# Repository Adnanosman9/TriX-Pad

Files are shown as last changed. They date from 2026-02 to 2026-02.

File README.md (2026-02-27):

<h1 align="center">
  TriXpad
</h1>

<h4 align="center">
  A custom, open-source mechanical macro-pad featuring an OLED screen.
</h4>

<div align="center">

  
  
  

</div>

<br>

##  Key Features

* **Brain:** Powered by the compact and capable **Seeed Studio XIAO RP2040**.
* **Firmware:** Runs on **KMK Firmware** (CircuitPython) for incredibly easy keymap customization without needing to recompile.
* **Display:** Integrated **0.91" SSD1306 OLED (128×64)** for real-time layer feedback, stats, or custom graphics.
* **Matrix:** A clean **3×3 Key Matrix** layout complete with diode orientation for robust anti-ghosting.

---

## Hardware Design

This project was built entirely from scratch, bridging custom PCB design with 3D modeling. 

### PCB (KiCad)
The board was routed and designed in KiCad to keep the footprint as minimal as possible while accommodating the XIAO RP2040 and OLED screen.

| Schematic | PCB Layout | 3D Render |
| :---: | :---: | :---: |
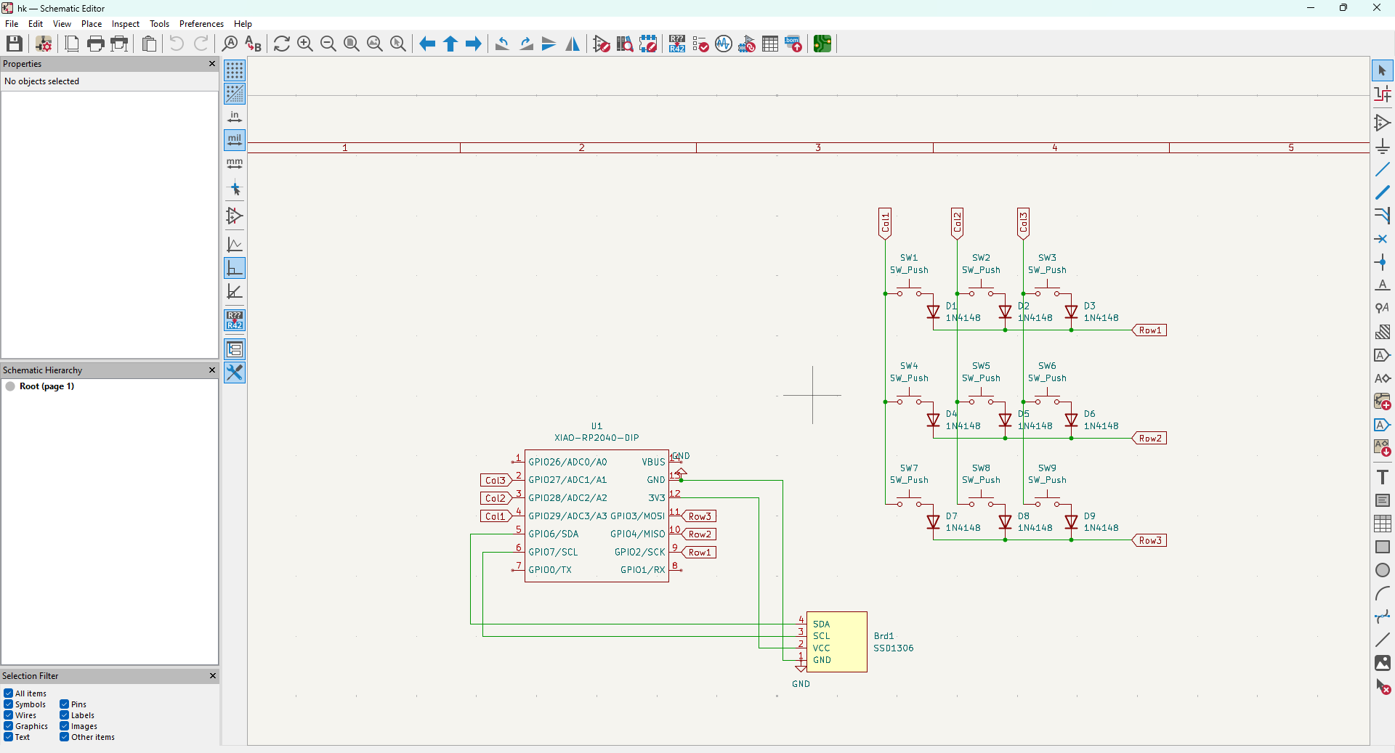
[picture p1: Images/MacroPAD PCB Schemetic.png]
Schematic
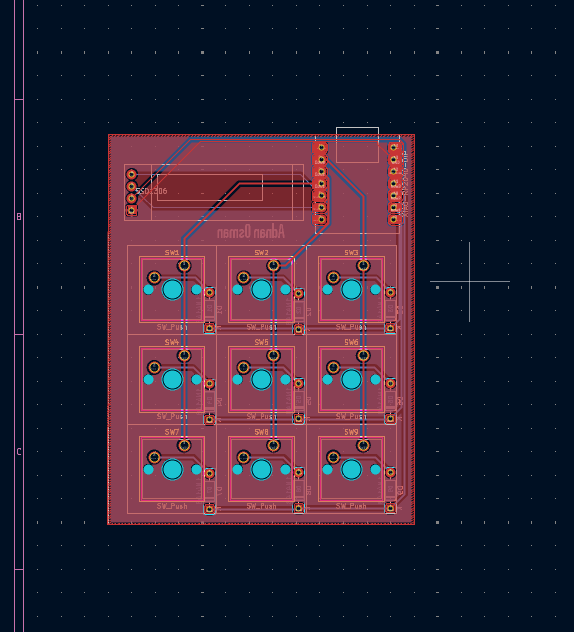
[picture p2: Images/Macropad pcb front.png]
PCB Front
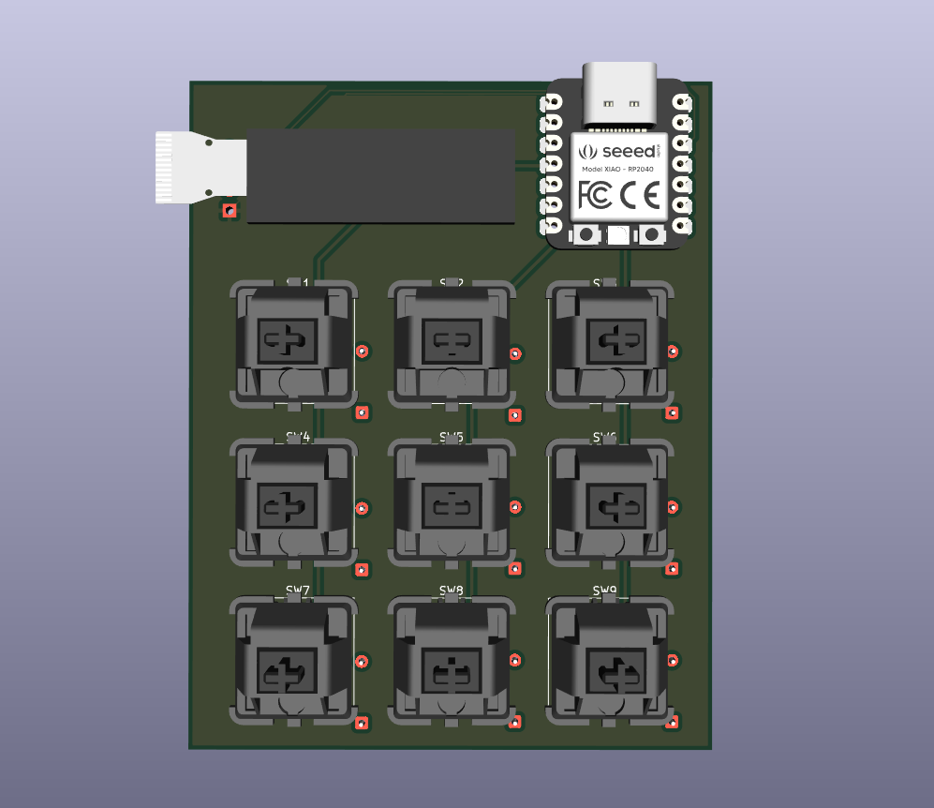
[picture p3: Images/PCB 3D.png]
PCB 3D
|  |  |  |

### Case (Fusion 360)
The enclosure was designed in Autodesk Fusion 360—marking my very first time diving into CAD! It features a sleek, two-part snap-fit/screw design to house the PCB and switches securely.

| Top Case | Bottom Case |
| :---: | :---: |
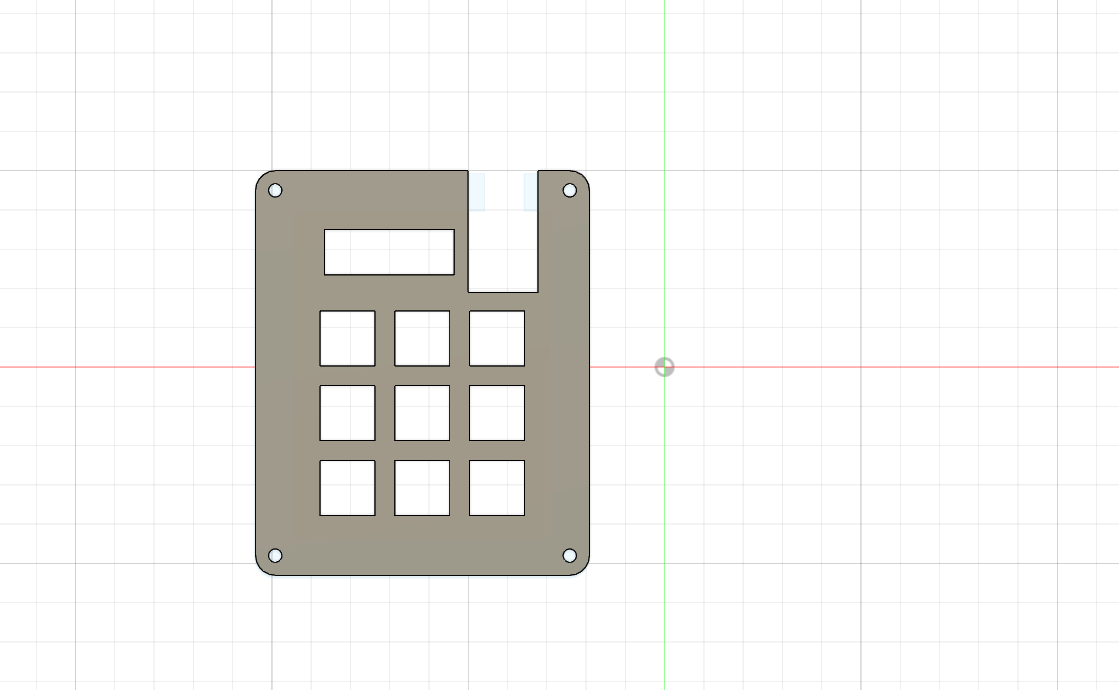
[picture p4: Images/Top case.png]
Case Top
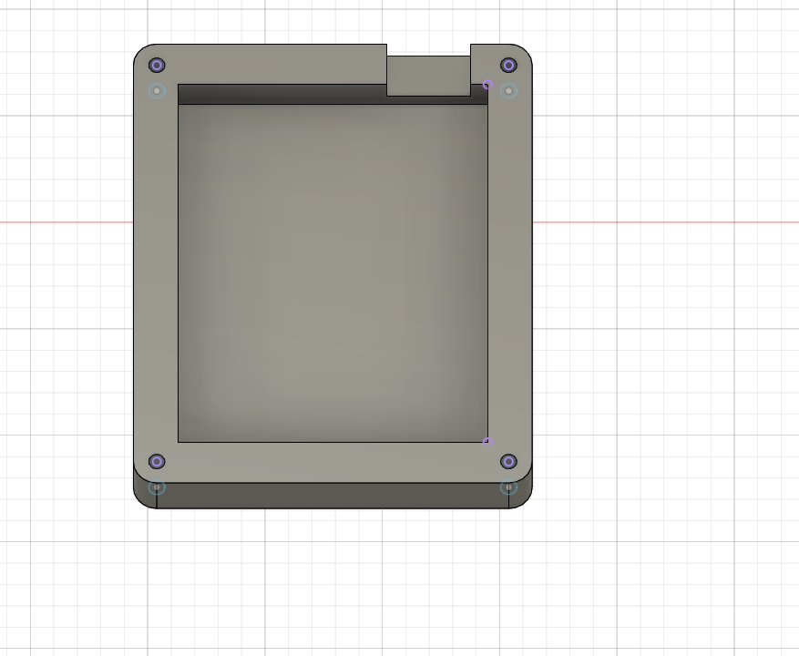
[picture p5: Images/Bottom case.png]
Case Bottom
|  |  |

###  The Final Build
<div align="center">
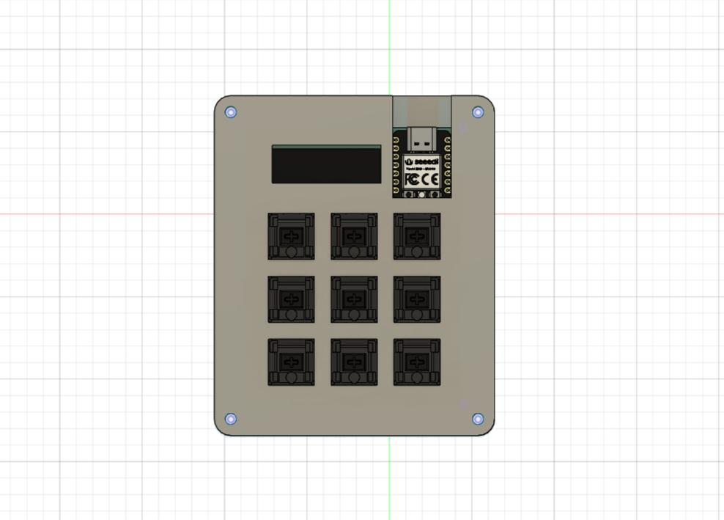
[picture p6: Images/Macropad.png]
Final Build
  
</div>

---

##  Bill of Materials (BOM)

Everything you need to build this macro-pad yourself. *(For full details, see the [`BOM.csv`](BOM.csv) file).*

| Component | Description / Item | Qty | Source |
| :--- | :--- | :---: | :--- |
| **Controller** | Seeed Studio XIAO RP2040 | 1 | [AliExpress](https://www.aliexpress.com/item/1005003901735765.html) |
| **Switches** | MX-Style (Cherry) | 9 | [AliExpress](https://www.aliexpress.com/item/1005008656717678.html) |
| **Display** | 0.91" SSD1306 OLED | 1 | [AliExpress](https://www.aliexpress.com/item/1005009334190029.html) |
| **Diodes** | 1N4148 Through-Hole | 9 | [Robotics BD](https://store.roboticsbd.com/components/1355-1n4148-diode-robotics-bangladesh.html) |
| **Keycaps** | Blank DSA Keycaps (Black) | 9 | [AliExpress](https://www.aliexpress.com/item/1005006114411137.html) |

---

##  Credits & Acknowledgments

This project wouldn't be possible without these incredible open-source tools and communities:

* **[KiCad](https://www.kicad.org/)** for the phenomenal open-source PCB design suite.
* **[Autodesk Fusion 360](https://www.autodesk.com/products/fusion-360/)** for the case design environment.
* **[Hack Club Blueprint](https://blueprint.hackclub.com/)** for the guide and inspiration. 
* Massive thanks to **Hack Club Bank** for the grant that funded the PCB and case manufacturing to bring this hardware to life!

<br>

<div align="center">
  Approved by Hack Club
  <br><br>
  <b>Designed by <a href="https://github.com/Adnanosman9">@Adnanosman</a></b>
</div>

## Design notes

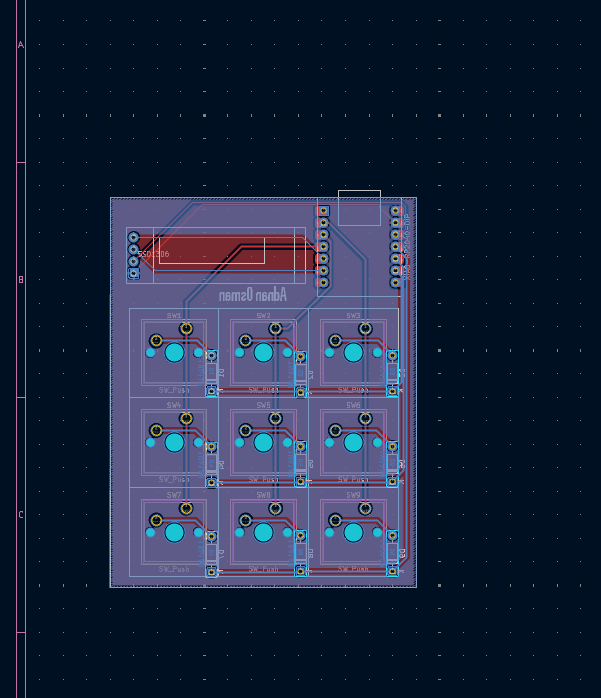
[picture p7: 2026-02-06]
Images/Macropad PCB back.png

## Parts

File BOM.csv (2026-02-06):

Component | Item | Quantity | Link
Controller | Seeed Studio XIAO RP2040 | 1 | https://www.aliexpress.com/item/1005003901735765.html?curPageLogUid=IyM167uC5ZPL
Switches | MX-Style -Cherry | 9 | https://www.aliexpress.com/item/1005008656717678.html?curPageLogUid=WpvRvEpise9v
Display | 0.91" SSD1306 OLED | 1 | https://www.aliexpress.com/item/1005009334190029.html?curPageLogUid=FVxMMdBZr2ks
Diodes | 1N4148 | 9 | https://store.roboticsbd.com/components/1355-1n4148-diode-robotics-bangladesh.html
Keycaps | Blank DSA Keycaps(Black) | 9 | https://www.aliexpress.com/item/1005006114411137.html?curPageLogUid=FdgYhFJXMlbC
PCB |  | 1 | https://www.nextpcb.com/?code=BanglaGECS

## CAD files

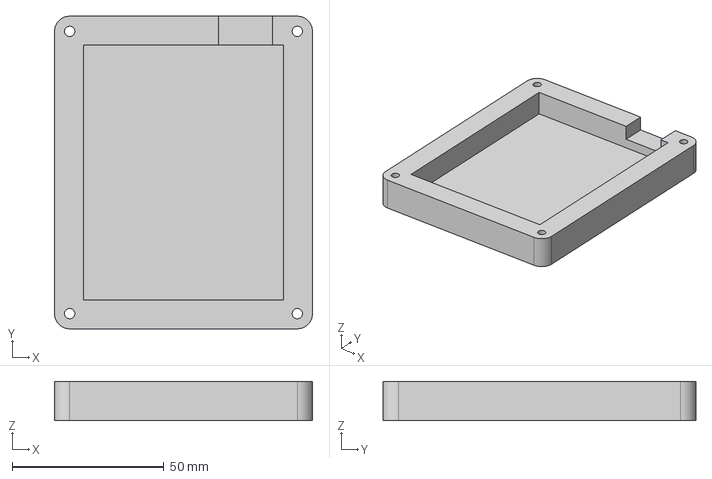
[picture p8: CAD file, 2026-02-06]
CAD/bottom case.step
85.0 x 103.0 x 13.0 mm

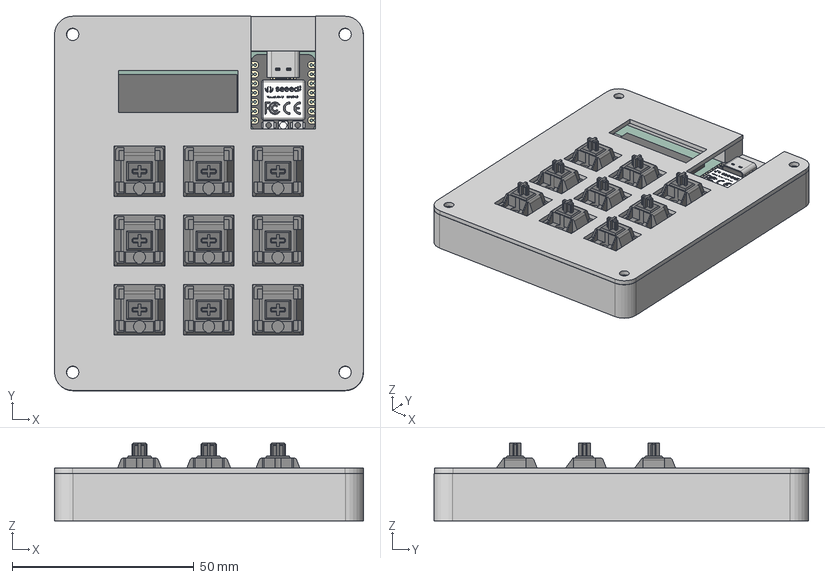
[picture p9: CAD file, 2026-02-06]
CAD/Macropad.step
85.1 x 103.1 x 21.3 mm

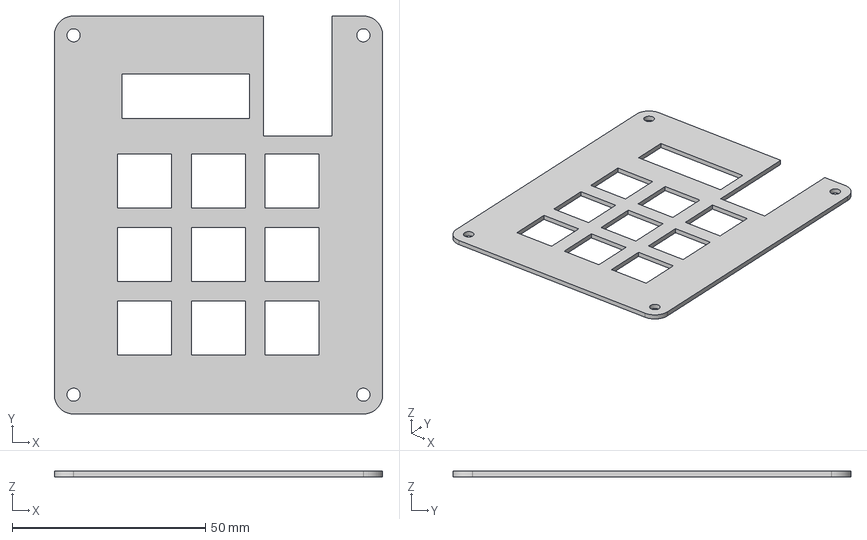
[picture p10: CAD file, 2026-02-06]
CAD/top case.step
85.0 x 103.0 x 1.50 mm

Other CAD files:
CAD/Macropad_file.f3d
CAD/bottom.f3d
CAD/top.f3d

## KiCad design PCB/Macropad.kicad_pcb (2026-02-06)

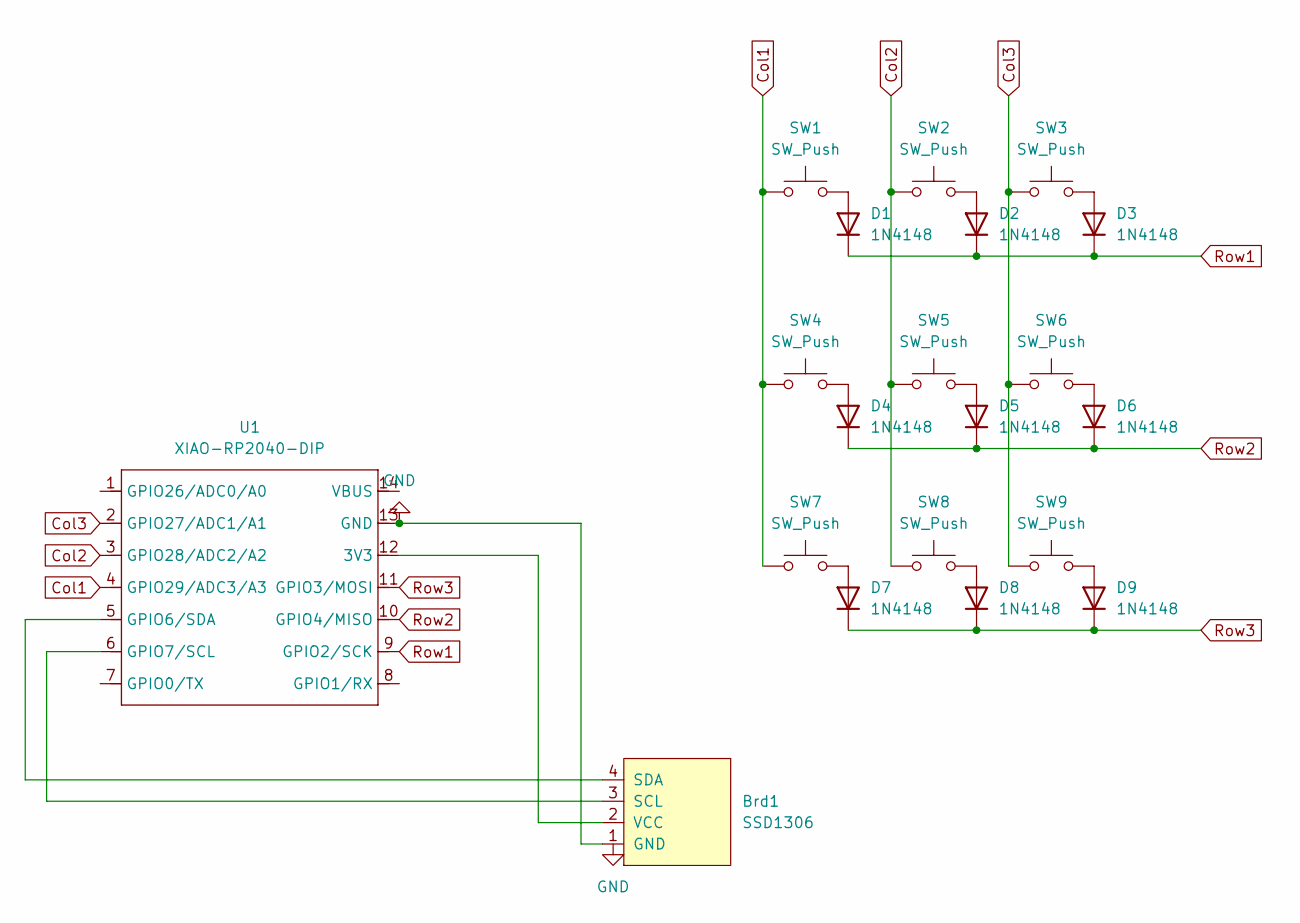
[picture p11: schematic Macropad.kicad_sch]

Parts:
Brd1: SSD1306; Adafruit_SSD1306
D1, D2, D3, D4, D5, D6, D7, D8, D9: 1N4148; D_DO-35_SOD27_P7.62mm_Horizontal
SW1, SW2, SW3, SW4, SW5, SW6, SW7, SW8, SW9: SW_Push; SW_Cherry_MX_1.00u_PCB
U1: XIAO-RP2040-DIP; Seeed_XIAO_RP2040

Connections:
Col1: SW1.1, SW4.1, SW7.1, U1.4 (GPIO29/ADC3/A3)
Col2: SW2.1, SW5.1, SW8.1, U1.3 (GPIO28/ADC2/A2)
Col3: SW3.1, SW6.1, SW9.1, U1.2 (GPIO27/ADC1/A1)
GND: Brd1.1 (GND), U1.13 (GND)
unnamed: Brd1.3 (SCL), U1.6 (GPIO7/SCL)
unnamed: Brd1.4 (SDA), U1.5 (GPIO6/SDA)
unnamed: Brd1.2 (VCC), U1.12 (3V3)
unnamed: D1.2 (A), SW1.2
unnamed: D2.2 (A), SW2.2
unnamed: D3.2 (A), SW3.2
unnamed: D4.2 (A), SW4.2
unnamed: D5.2 (A), SW5.2
unnamed: D6.2 (A), SW6.2
unnamed: D7.2 (A), SW7.2
unnamed: D8.2 (A), SW8.2
unnamed: D9.2 (A), SW9.2
Row1: D1.1 (K), D2.1 (K), D3.1 (K), U1.9 (GPIO2/SCK)
Row2: D4.1 (K), D5.1 (K), D6.1 (K), U1.10 (GPIO4/MISO)
Row3: D7.1 (K), D8.1 (K), D9.1 (K), U1.11 (GPIO3/MOSI)

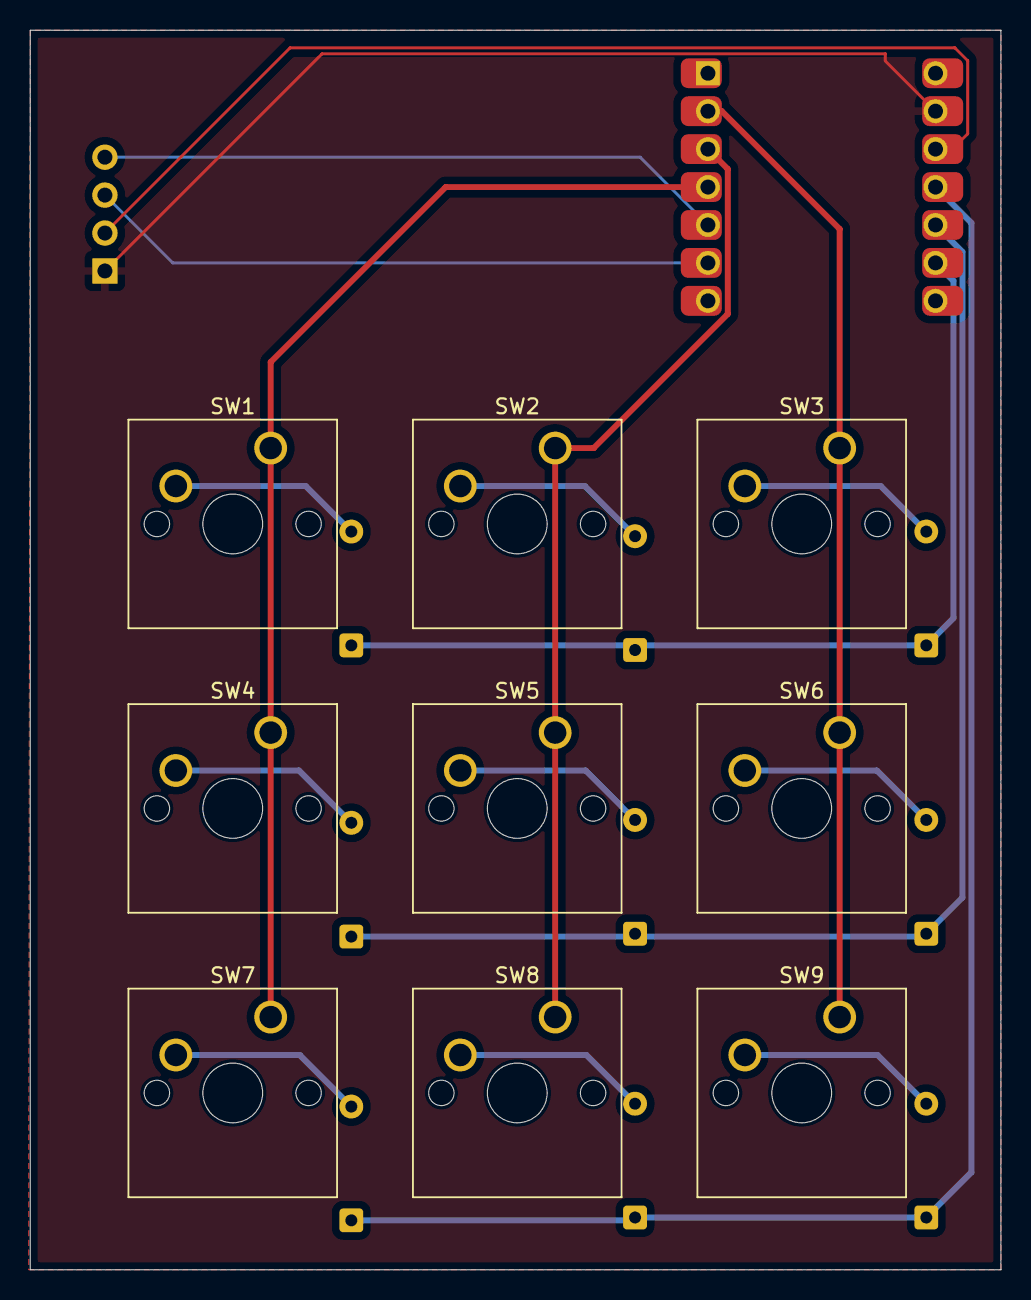
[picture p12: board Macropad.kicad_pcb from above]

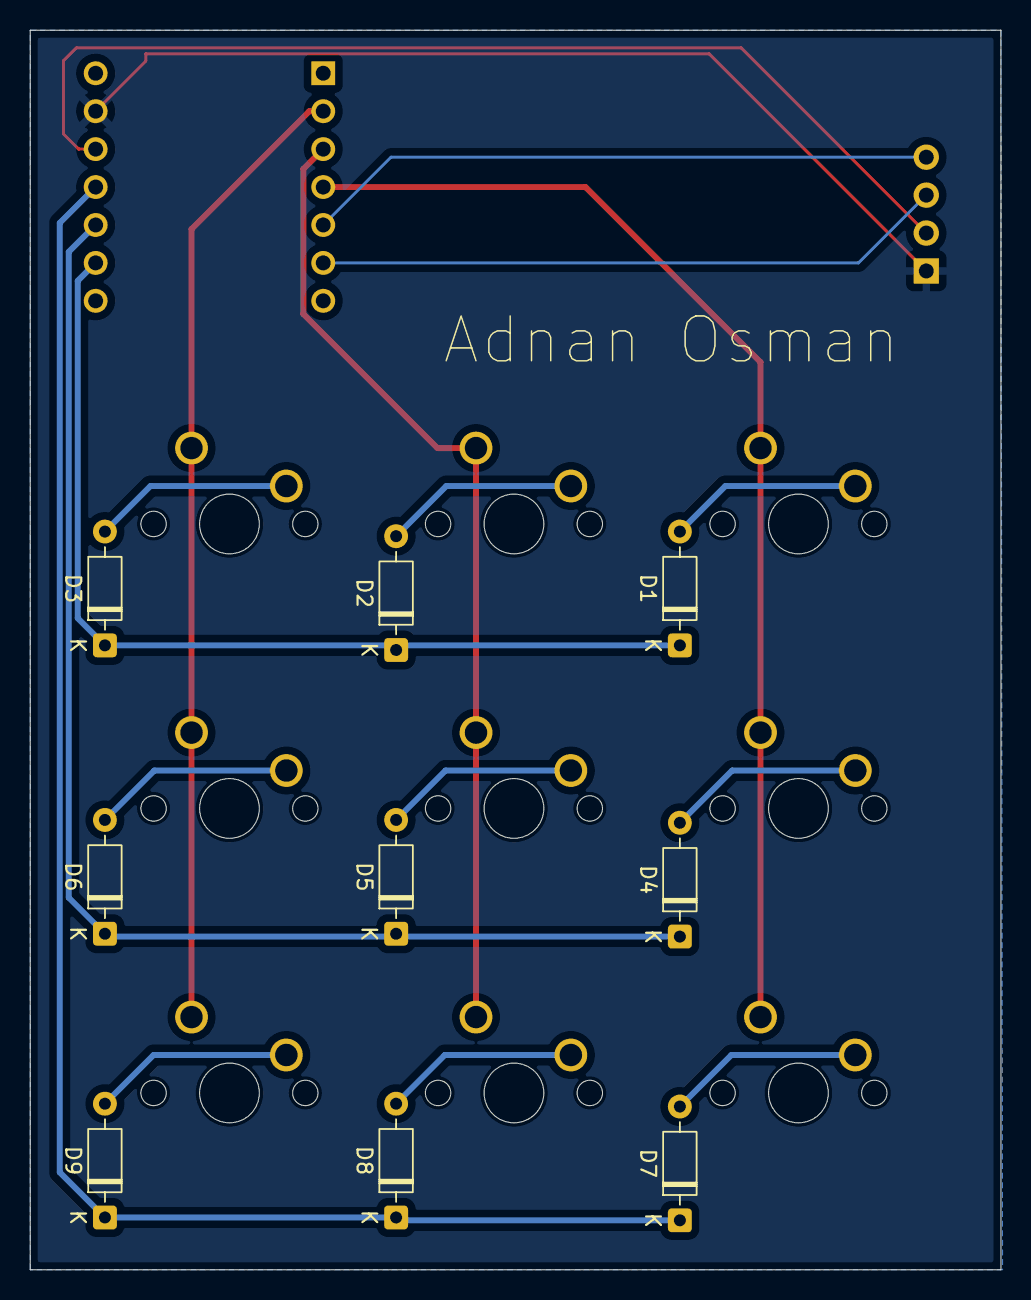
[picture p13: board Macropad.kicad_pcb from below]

Board: 2 copper layers, 65.0 x 83.0 mm, 20 parts (9 on the bottom side), 19 nets.

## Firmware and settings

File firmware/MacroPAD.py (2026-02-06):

import board
from kmk.kmk_keyboard import KMKKeyboard
from kmk.keys import KC
from kmk.scanners import DiodeOrientation
from kmk.extensions.pegasus_oled import PegasusOLED

pad = KMKKeyboard()
pad.row_pins = (board.D2, board.D4, board.D3)
pad.col_pins = (board.D10, board.D8, board.D9)

pad.diode_orientation = DiodeOrientation.ROW2COL
oled_ext = PegasusOLED(
    i2c_device=board.I2C(),
    width=128,
    height=32,
)
pad.extensions.append(oled_ext)

pad.keymap = [
    [
        KC.N7, KC.N8, KC.N9,
        KC.N4, KC.N5, KC.N6,
        KC.N1, KC.N2, KC.N3,
    ]
]

if __name__ == '__main__':
    pad.go()
